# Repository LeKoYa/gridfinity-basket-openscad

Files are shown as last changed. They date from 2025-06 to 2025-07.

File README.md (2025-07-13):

# Gridfinity Basket in OpenSCAD



An openscad script for stackable baskets with a gridfinity base on the inside. Includes many customization options.

The model and various example baskets are also available on makerworld/printables. The site on makerworld also supports the parametric model maker to easily create baskets with different options directly on the site.

[Makerworld site](https://makerworld.com/en/models/1542416-stackable-gridfinity-storage-basket-parametric)

[Printables site](https://www.printables.com/model/1335756-stackable-gridfinity-storage-basket-parametric)

# Customization options
Below is a list of all possible customization options. Although it is possible for most options to set a value outside of the allowed range, in almost all cases it is not a good idea.

### General options
| Parameter | Description | Type | Default | Allowed Values / Range |
| --- | --- | --- | --- | --- |
| `UseMulticolor` | Add color to the model in three different sections (Can be used together with the openscad .3mf export for multi-color printing) | `bool` | `false` | `true`, `false` |
| `UseGridfinityBase` | Include a Gridfinity base inside the basket or keep the bottom flat | `bool` | `true` | `true`, `false` |
| `GridSize` | Grid size in `[X, Y, Z]` format, in multiples of 1U gridfinity units | `array`  | `[2,2,4]` | Integers ≥ 1 |
| `Padding` | Padding between edge of Gridfinity base and basket walls (zero padding makes bins with the same size as the basket hard to put in/take out)| `number` | `1` | `0` to `10`, step `0.1` |
| `WallThickness` | Wall thickness of the basket | `number` | `1.2` | `0.4` to `2`, step `0.1` |
| `AdditionalFloorHeight` | Additional floor height added to bottom of basket | `number` | `1` | `0` to `3`, step `0.04` |
| `SolidFloor` | Make floor solid (requires `FloorHeight > 0`) | `bool` | `true` | `true`, `false` |
| `MagnetDiameter` | Diamenter of the magnets. If set to zero, no magnet holes will be created. Increase this value to add some tolerance for magnet insertion. | `number` | `6.5` | `0` to `8`, step `0.05` |
| `MagnetHeight` | Height of the magnets. If set to zero, no magnet holes will be created. Increase this value to add some tolerance for magnet insertion. | `number` | `2.1` | `0` to `4`, step `0.05` |
| `AddMagnetChamfer` | Add additional chamfers around magnet holes to help with insertion | `bool` | `false` | `true`, `false` |

### WallPattern options
| Parameter | Description | Type | Default | Allowed Values / Range |
| --- | --- | --- | --- | --- |
| `WallPattern` | Wall pattern type | `int` | `1` | `0: None`, `1: HexGrid`, `2: Grid` |
| `PatternSize` | Pattern feature size | `number` | `8` | `4` to `15`, step `0.5`  |
| `PatternTopDist` | Minimum distance from the top of the pattern to the start of the stacking lip | `number` | `3` | `0` to `10`, step `0.1` |
| `PatternBotDist` | Minimum distance from the bottom of the pattern to the baseplate | `number` | `1.5` | `0` to `10`, step `0.1` |
| `PatternSideDist` | Minimum distance from the pattern sides to the start of the basket outer corner | `number` | `2` | `0` to `10`, step `0.1` |
| `PatternMinDist` | Minimum distance between patterns | `number` | `2` | `0.5` to `5`, step `0.1` |
| `GridPatternRadius` | Outer radius of grid pattern (not applicable to other patterns) | `number` | `3` | `0` to `10`, step `0.5`  |

### Handle options
| Parameter | Description | Type | Default | Allowed Values / Range |
| --- | --- | --- | --- | --- |
| `AddHandle` | Add a handle to the sides of the basket | `bool` | `true`  | `true`, `false` |
| `HandleWidth` | Width of the handle | `number` | `35`  | `20` to `100`, step `1` |
| `HandleHeight` | Height of the handle | `number` | `11`  | `11` to `30`, step `1` |
| `HandleCorderRadius` | Radii of the corners on the inside of the handles | `number` | `4`  | `0` to `5`, step `0.5` |
| `HandleBorder` | Minimum border size around the handle. The border may be larger to accommodate the wall pattern | `number` | `3`  | `2` to `5`, step `0.5` |

### Stacking options
| Parameter | Description | Type | Default | Allowed Values / Range |
| --- | --- | --- | --- | --- |
| `Standoff` | Vertical standoff height at the bottom of the basket (the part that sticks into another basket when stacked ontop of eachother) | `number` | `1` | `1` to `2`, step `0.1` |
| `TopPadding`  | Extra room above bins for stacking | `number` | `2` | `0.5` to `5`, step `0.1` |
| `XYTolerance` | XY-axis tolerance (should keep as-is in most-cases) | `number` | `0.5` | `0.2` to `1`, step `0.05` |
| `ZTolerance`  | Z-axis tolerance (should keep as-is in most-cases) | `number` | `0.25`  | `0.25` |

# Additional tips
- The Grid pattern can be quite fragile. Use a large `PatternMinDist` and possibly a larger `WallThickness`. 
- No need for supports or brim when printing the baskets.
- The HandleBorder sets the lower limits for the border around the handle. It might be increased so that the chosen pattern and the area for the handle line up. Otherwise the border of the handle could be floating and couldn't be printed without support.

# Example baskets
#### Animation of various settings
Example Baskets

#### 3_2_6 Basket with hexpattern and gridfinity base
3_2_6_hexpattern

#### 3_2_4 Basket with gridpattern and without gridfinity floor
3_2_4_gridpattern_nogridfinity

#### Two 3_2_6 Hex Baskets stacked on top of each other
Two Baskets stacked on top of each other

#### 5_3_8 Basket with hollow floor and no wall pattern.
5_3_8 Basket with hollow floor and no wall pattern

#### Optional Magnet holes with the option for additional chamfers
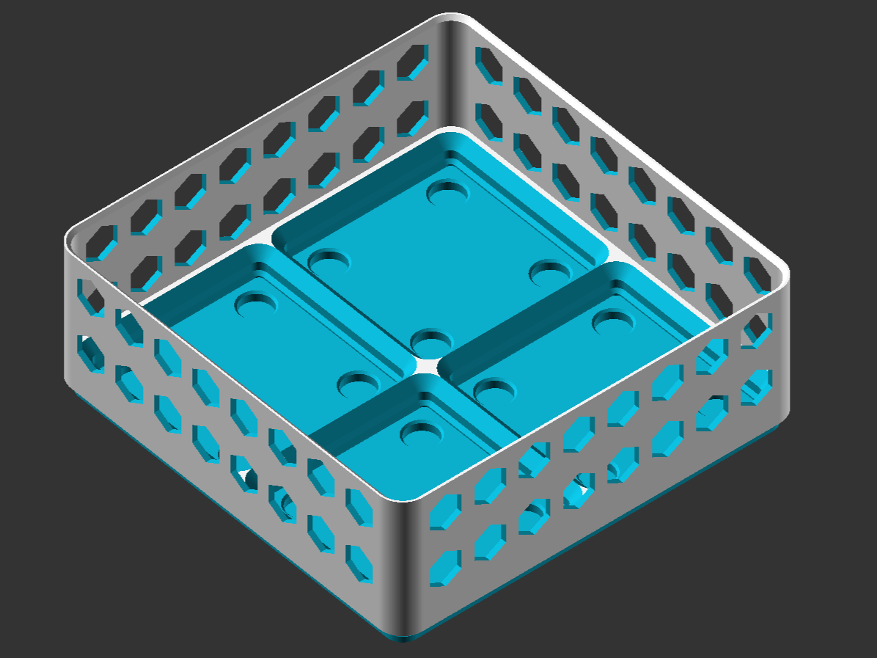
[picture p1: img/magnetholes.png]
Example basket with magnet holes


#### 3_3_8 Basket with hexpattern and handles on the sides
3_3_8 Basket with hexpattern and handles

# Acknowledgements
The base generation is inspired and adapted from the [gridfinity-rebuilt-openscad project](https://github.com/kennetek/gridfinity-rebuilt-openscad). 

The general idea is based on the [Gridfinity-baseplate-basket-parametric](https://www.printables.com/model/970197-gridfinity-baseplate-basket-parametric) model by Blaise's Workshop. In comparison to that model, the gridfinity basket here offers much more customization options and various improvements like the support for padding and different wall sizes.

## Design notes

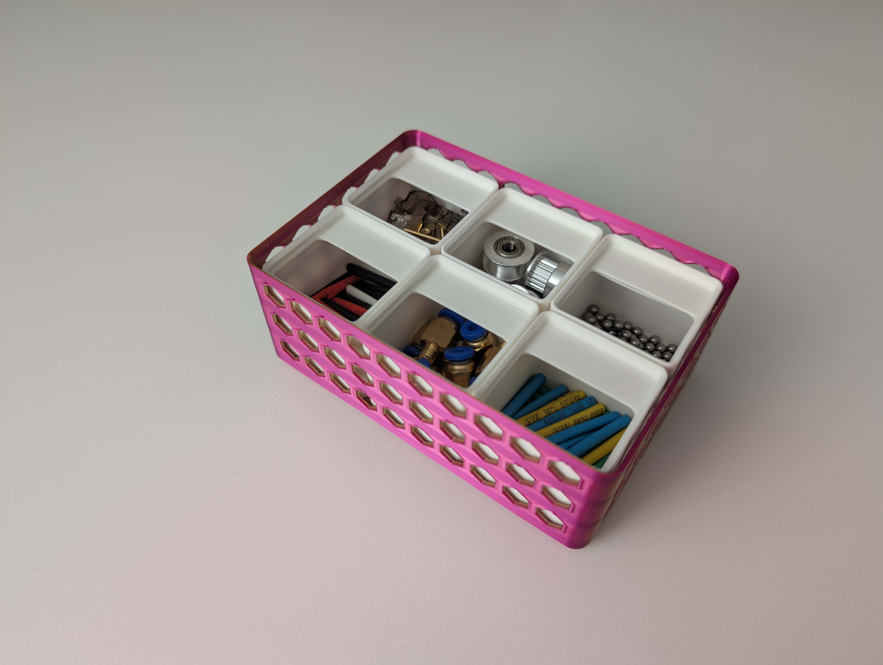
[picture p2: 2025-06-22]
img/3_2_6_hex_withbins.jpg

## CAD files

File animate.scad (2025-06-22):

include <gridfinityBasket.scad>;

Render = true;

// Gridsize
GridSize = [1+floor($t*360/120), 1+floor($t*360/120), 1+floor($t*360/60)];

// Pattern feature size
PatternSize = 3+floor($t*360/5%15); // [4:0.5:15]

// Wall Pattern
WallPattern = floor($t*360/120); // [0:None, 1:HexGrid, 2:Grid]

$fa = 2;
$fs = 0.2;
$vpt = [0, 0, 20];
$vpr = [70, 0, 45+360 * $t];
$vpd = 350;

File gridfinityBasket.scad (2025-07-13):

/*
Some of the functions and calculations were adapted from the gridfinity-rebuilt-openscad project
See: https://github.com/kennetek/gridfinity-rebuilt-openscad
*/

$fa = 2;
$fs = 0.2;

// ===== Specification ===== //
// most of these are from: https://gridfinity.xyz/specification/

/* [Hidden] */

// x,y dimensions of a gridfinity cell
BASEPLATE_DIMENSIONS = [42, 42];

// height of a baseplate 
BASEPLATE_HEIGHT = 5;

// outer diameter of the baseplate
BASEPLATE_OUTER_DIAMETER = 8;

// side profile of the baseplate
BASEPLATE_PROFILE = [
    [0, 0], // Innermost bottom point
    [0.7, 0.7], // Up and out at a 45 degree angle
    [0.7, (0.7+1.8)], // Straight up
    [(0.7+2.15), (0.7+1.8+2.15)], // Up and out at a 45 degree angle
];

// some calculations...
BASEPLATE_OUTER_RADIUS = BASEPLATE_OUTER_DIAMETER / 2;
BASEPLATE_INNER_RADIUS = BASEPLATE_OUTER_RADIUS - BASEPLATE_PROFILE[3].x;
BASEPLATE_INNER_DIAMETER = BASEPLATE_INNER_RADIUS * 2;

// distance from center of magnet hole to edge of baseplate section
MAGNET_EDGE_DIST = 8;

// ===== Parameters ===== //

/* [Hidden]*/
// Minimum wall thickness
MinWallThickness = 0.4;

// Additional height from the bottom of the magnet holes to the top of the added floor.
// Necessary in case the AdditionalFloorHeight is set to zero.
MinMagnetFloorHeight = 0.4;

// only used for use with the animate.scad script. Don't change this here
// can also be set to true for developing or testing.
// turn off for export
Render = false;

/* [General Settings] */

// Add color to the model
UseMulticolor = false;

// Include a gridfinity base inside the basket?
UseGridfinityBase = true;

// Gridsize
GridSize = [3,3,6]; // [1:1:]

// Padding between edge of gridfinity base and the basket walls
Padding = 1; // [0:0.1:10]

// Wall Thickness of the Basket
WallThickness = 1.2; // [0.4:0.1:2]

// Additional floor height added to the bottom of the basket. 
AdditionalFloorHeight = 1; // [0:0.04:3]

// Solid floor? Requires AdditionalFloorHeight > 0 to work
SolidFloor = true;

// Diamenter of the magnets. If set to zero, no magnet holes will be created. Increase this value to add some tolerance for magnet insertion.
MagnetDiameter = 6.1; // [0:0.05:8]

// Height of the magnets. If set to zero, no magnet holes will be created. Increase this value to add some tolerance for magnet insertion.
MagnetHeight = 2.1; // [0:0.05:4]

// Add additional chamfers around magnet holes to help with insertion
AddMagnetChamfer = false;

/* [WallPattern Settings] */

// Wall Pattern
WallPattern = 1; // [0:None, 1:HexGrid, 2:Grid]

// Pattern feature size
PatternSize = 8; // [4:0.5:15]

// Minimum distance from the top of the pattern to the start of the stacking lip
PatternTopDist = 3; // [0:0.1:10]

// Minimum distance from the bottom of the pattern to the baseplate
PatternBotDist = 1.5; // [0:0.1:10]

// Minimum distance from the pattern sides to the start of the basket outer corner
PatternSideDist = 2; // [0:0.1:10]

// Minimum distance between patterns
PatternMinDist = 2; // [0.5:0.1:5]

// Outer radius of grid pattern (has no effect on other patterns)
GridPatternRadius = 4; // [0:0.5:10]

/* [Handle Settings] */

// Add a handle to the sides of the basket
AddHandle = true;

// Width of the handle
HandleWidth = 35; // [20:1:100]

// Height of the handle
HandleHeight = 11; // [11:1:30]

// Radii of the corners on the inside of the handles
HandleCornerRadius = 4; // [0:0.5:5]

// Minimum border around the handle. The border may be larger to accommodate the wall pattern.
HandleBorder = 3; // [2:0.5:5]

/* [Stacking Settings] */

// How far down a basket reaches into a basket under it. Increasing this value decreses wiggle when stacking baskets. 
Standoff = 1; // [1:0.1:2]

// extra room between top of any bin and bottom of another basket stacked on top
TopPadding = 2 ; // [0.5:0.1:5]

// XY tolerance (leave as-is in most cases)
XYTolerance = 0.5; // [0.2:0.05:1]

// Z tolerance (lave as-is in most cases)
ZTolerance = 0.25; 


// ===== Calculations ===== //

/* [Hidden] */

// Necessary height needed for magnets. 
magnet_clearance = (MagnetDiameter > 0 && MagnetHeight > 0 && UseGridfinityBase && SolidFloor) ? MagnetHeight + MinMagnetFloorHeight : 0;

total_grid_size_mm = [BASEPLATE_DIMENSIONS.x * GridSize.x, BASEPLATE_DIMENSIONS.y * GridSize.y];
total_inner_size_mm = foreach_add(total_grid_size_mm, 2 * Padding);
total_outer_size_mm = foreach_add(total_inner_size_mm, 2 * WallThickness);

// Total grid height: 5mm baseplate, 2mm for 1u, 4.4mm for stacking lip, nU*7mm
total_grid_height_mm = BASEPLATE_HEIGHT + 2 + 4.4 + 7*(GridSize.z-1); 

// another basket sits inside by standoff mm and even further by ztolerance, starting from the lowest point of the top stacking lip. 
// Added top padding increases distance between bins and top of another basket stacked on top
// Also add some height for magnets if necessary
total_height_mm = total_grid_height_mm + AdditionalFloorHeight + Standoff + ZTolerance + (WallThickness-MinWallThickness) + TopPadding + magnet_clearance;

// The total height of the bottom stacking lip
bottom_stacking_lip_height = Standoff + ZTolerance + WallThickness + XYTolerance;

// Total height from the bottom of the basket up untip the top of the baseplate
total_baseplate_height_mm = BASEPLATE_HEIGHT + AdditionalFloorHeight + magnet_clearance;

// Total area needed for the handles (including border)
total_handle_area = [
    min(HandleWidth+2*HandleBorder, total_grid_size_mm.y-2*BASEPLATE_OUTER_RADIUS),
    min(HandleHeight+2*HandleBorder, total_grid_height_mm-BASEPLATE_HEIGHT)
];


// ===== Helper functions and modules ===== //

/*
Adds a value to every element of a list
list: List to add values to
to_add: Value to add
*/
function foreach_add(list, to_add) = 
    [for (item = list) item + to_add];

/*
Affine translation with vector for use with `multmatrix()`
*/
function affine_translate(vector) = [
    [1, 0, 0, vector.x],
    [0, 1, 0, vector.y],
    [0, 0, 1, vector.z],
    [0, 0, 0, 1]
];

/*
Calculates the magnitude of a 2d or 3d vector
*/
function vector_magnitude(vector) =
    sqrt(vector.x^2 + vector.y^2 + (len(vector) == 3 ? vector.z^2 : 0));

/*
Converts a 2d vector into an angle
Just a wrapper around atan2
*/
function atanv(vector) = atan2(vector.y, vector.x);

function _affine_rotate_x(angle_x) = [
    [1,  0, 0, 0],
    [0, cos(angle_x), -sin(angle_x), 0],
    [0, sin(angle_x), cos(angle_x), 0],
    [0, 0, 0, 1]
];
function _affine_rotate_y(angle_y) = [
    [cos(angle_y),  0, sin(angle_y), 0],
    [0, 1, 0, 0],
    [-sin(angle_y), 0, cos(angle_y), 0],
    [0, 0, 0, 1]
];
function _affine_rotate_z(angle_z) = [
    [cos(angle_z), -sin(angle_z), 0, 0],
    [sin(angle_z), cos(angle_z), 0, 0],
    [0, 0, 1, 0],
    [0, 0, 0, 1]
];

/*
Affine transformation matrix equivalent to `rotate`
Equivalent to `rotate([0, angle, 0])`
For use with `multmatrix()`
*/
function affine_rotate(angle_vector) =
    _affine_rotate_z(angle_vector.z) * _affine_rotate_y(angle_vector.y) * _affine_rotate_x(angle_vector.x);


/*
Create a rectangle with rounded corners by sweeping a 2d object along a path
Centered on origin
Result is on the x,y plane
Expects children to be a 2D shape in Q1 of x,y plane
size: dimensions of the resulting object as [x,y]
*/
module sweep_rounded(size) {
    half_x = size.x/2;
    half_y = size.y/2;
    path_points = [
        [-half_x, -half_y],
        [-half_x, half_y],
        [half_x, half_y],
        [half_x, -half_y],
        [-half_x, -half_y]
    ];
    path_vectors = [
        path_points[1] - path_points[0],
        path_points[2] - path_points[1],
        path_points[3] - path_points[2],
        path_points[4] - path_points[3]
    ];

    // These contain the translations, but not the rotations
    // OpenSCAD requires this hacky for loop to get accumulate to work!
    first_translation = affine_translate([path_points[0].y, 0,path_points[0].x]);
    affine_translations = concat([first_translation], [
        for (i = 0, a = first_translation;
            i < len(path_vectors);
            a=a * affine_translate([path_vectors[i].y, 0, path_vectors[i].x]), i=i+1)
        a * affine_translate([path_vectors[i].y, 0, path_vectors[i].x])
    ]);

    // Bring extrusion to the xy plane
    affine_matrix = affine_rotate([90, 0, 90]);

    walls = [
        for (i = [0 : len(path_vectors) - 1])
        affine_matrix * affine_translations[i]
        * affine_rotate([0, atanv(path_vectors[i]), 0])
    ];
    union() {
        for (i = [0 : len(walls) - 1]){
            multmatrix(walls[i])
                linear_extrude(vector_magnitude(path_vectors[i]))
                    children();

            // Rounded Corners
            multmatrix(walls[i] * affine_rotate([-90, 0, 0]))
                rotate_extrude(angle = 90, convexity = 4)
                    children();
        }
    }
}
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

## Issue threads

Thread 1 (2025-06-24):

[Feature Request] Press Fit Magnet Slots

jwmann, 2025-06-24:
Already mentioned this on Reddit but I figured I'd open an official ticket, just so we can keep track of it.

My main inspiration for the press fit style was the ones used in the [Gridfinity Redefined](https://www.printables.com/model/413761-gridfinity-refined) set.

Looks like this:
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

They have the magnets inserted from the bottom, that's not really a requirement for me- personally I kinda like them inserted from the top, since it's easier to print, and slightly stronger magnetically.

The little cavity in the corners of the holes also allows the user to pry the magnet out if needed as well, just a nice bonus.
Let me know your thoughts

LeKoYa, 2025-07-07:
I've only just seen your ideas for improvement. I've already added support for magnets recently in 3fcd21368dddf78de1b15f52c08dc10d697b9356, so this should work.
Currently only inserting from the top is supported and i'm not sure how likely it is that i will add the ability to insert magnets from the bottom. The little cavity looks nice, i'll also probably look into that some time in the future. Feel free to work on this if you want.

jwmann, 2025-07-09:
> Feel free to work on this if you want.

I really wish I could, I tried setting up OpenSCAD on my M1 Macbook, and it's _rough_; just rendering the file with all defaults took literally 10 minutes. Couldn't believe it.

I think it's because it runs in Rosetta/Emulation mode from the Intel version but I'm not sure.
What's your setup like?

Closed 2025-07-07.

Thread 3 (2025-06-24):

[Enhancement] The ability to change PatternEdgeDist independently horizontally & vertically

jwmann, 2025-06-24:
Right now `PatternEdgeDist` can only apply to both horizontal edges and vertical edges.

It would be fantastic to have the option to define vertical and horzontal separately.
Perhaps a `PatternEdgeDistX` & `PatternEdgeDistY`.

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

LeKoYa, 2025-07-07:
Good idea, should not be too difficult. I'll look into it.

LeKoYa, 2025-07-07:
It's now possible to set the bot, top and side distances independently from each other. See some examples:

##### PatternBotDist=0, PatternTopDist=0, PatternSideDist=0
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

##### PatternBotDist=2, PatternTopDist=10, PatternSideDist=0
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

##### PatternBotDist=0, PatternTopDist=0, PatternSideDist=10
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

jwmann, 2025-07-09:
Beautiful! Thank you 🙏

Closed 2025-07-07.

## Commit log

2025-06-22 Add first iteration of the gridfinity basket script
    [gridfinityBasket.scad]
2025-06-22 updated the script and added support for an animation script
    [animate.scad, gridfinityBasket.scad]
2025-06-22 Updated readme and default values
    [gridfinityBasket.scad]
2025-06-23 Added support for magnets and chamfers around magnet holes
    [gridfinityBasket.scad]
2025-06-23 Added example image of magnet holes and chamfer
2025-06-23 Small parameter range fix for ZTolerance
    [gridfinityBasket.scad]
2025-06-23 Added link to printables
2025-07-07 Changed the default values for the magnet holes
    [gridfinityBasket.scad]
2025-07-07 Made it possible to change the distance from the pattern to the edges independently
    [gridfinityBasket.scad]
2025-07-09 Added the option for handles. Changes to the way the grid pattern is generated.
    [gridfinityBasket.scad]
2025-07-09 Example images of printed basket with handles
    Added two example images of a printed basket with handles
2025-07-13 Bugfixes and improvements to gridpattern
    [gridfinityBasket.scad]
2025-07-13 Updates to readme and parameter comments
    [gridfinityBasket.scad]

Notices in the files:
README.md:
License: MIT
